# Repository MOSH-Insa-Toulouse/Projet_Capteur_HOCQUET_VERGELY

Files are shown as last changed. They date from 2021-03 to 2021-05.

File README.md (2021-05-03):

# Projet Banc de tests 

## Sommaire
<!-- TOC depthFrom:2 -->
  - [1. Description](#1-description)
  - [2. Installation](#2-installation)
  - [3. Code Arduino](#3-code-arduino)
  - [4. Shield KICAD](#4-shield)
  - [5. Application Android](#5-application-android)
  - [6. Etalonnage](#6-Etalonnage)
  - [7. Datasheet](#7-datasheet)
  - [8. Les auteurs](#8-les-auteurs)
<!-- /TOC -->

## 1. Description
Ce répertoire contient toutes les ressources nécessaires au  projet "du capteur au banc de tests" 2021 du Génie Physique de l'INSA de Toulouse. Ce projet est basé sur l'utilisation d'un capteur en graphite, il exploite la dépendance entre la conductivité électrique et l’espace moyen entre les particules au sein d’un système granuleux. L'application de forces entraîne la déformation de l'échantillion, ce qui affecte la distance entre les particules et donc la variataion de la conductivité/resistance globale de l'échantillion.
La chaîne de mesure est basée sur l'acquisition d'un signal associé à la variation de résistance du capteur. Notre shield permet de conditionner, filtrer et amplifier (ampli transimpédance) le signal afin de transmettre une tension exploitable par une carte arduino UNO. Par ailleurs, il fait aussi le lien entre la carte et les différents modules : module bluetooth, encodeur rotateur, écran oled. 
Les mesures sont aussi transmises en bluetooth et interfacées sur une application mobile que nous avons conçue sur MIT App Inventor.

## 2. Installation

### Préparation du shield 
Utilisez le fichier gerber pour imprimer le shield, puis utilisez le schéma et fiche technique pour le choix et le positionnement des composants. Une fois les composants et les pattes soudées, vous pouvez brancher le shield sur l'arduino UNO.

### Codes 
Vous pouvez ensuite récupérer le code arduino depuis le fichier "Code Arduino" de ce répertoire et directement le téléverser sur la carte. Concernant l'application mobile, il vous suffit de récupérer et d'installer le .apk placé dans le fichier "application mobile" du répertoire.
Vous êtes maintenant prêts à réaliser vos premières mesures !

## 3. Code Arduino

Notre code Arduino (C++) que vous retrouverez dans le fichier du même nom, permet : de lire la tension tension de sortie de l'ampli transimpédance sur 10 bits, d'afficher le signal sur un écran OLED 128x64 en Volts ou en Ohm sur 10 bits, de transmettre la tension par bluetooth sur 1 otect à travers le module hc-05 et d'acquerir les rotations d'un encodeur rotatoire afin de changer l'affichage de l'écran OLED.

## 4. Shield

Le shield a été conçu sous KiCad, il contient un amplificateur transimpédance adapté à notre utilisation, ainsi que des socles pour alimenter et communiquer avec les différents modules. Vous pouvez retrouver l'ensemble du projet, et les fichiers nécessaires à l'impression dans le fichier "Shield_KiCad".

## 5. Application Android

Nous avons prototypé une application mobile capable de recevoir la tension associée à la mesure sur 1 octet et de la traiter. Elle dispose de plusieurs options qui permettent de convertir la tension en resistance, de fixer R0 (la résistance sans contrainte appliquée) et d'afficher en temps réel l'évolution relative de la resistance dans un graphique. Il est aussi possible de régler l'échelle du graphique pour mieux visualiser les variations.

## 6. Etalonnage

Un protocole d'étalonnage conçu spécialement pour notre banc de test est présent dans le fichier "Procédure d'étalonnage", il explique en détail la procédure suivie et le matériel que nous conseillons pour obtenir des résultats optimaux. 

## 7. Datasheet

Les conditions d'utilisation, les résultats attendus,  ainsi que les détails sur chaque partie de la chaîne de mesures sont donnés dans la datasheet que vous pouvez retrouver dans le fichier au même nom. 

## 8. Les auteurs

Projet réalisé par des étudiants en 4 ième année du Génie Physique de l'INSA de Toulouse:

**Henri Hocquet et Fabien Vergely**

- Mail : _henrii.hocquet@gmail.com_

- Mail : _fabien.vergely@gmail.com_

Si vous avez des questions n'hésitez pas ;)

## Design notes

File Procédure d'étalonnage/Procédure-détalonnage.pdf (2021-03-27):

Fabien Vergely Henri Hocquet 4GP

### Procédure d’étalonnage de la chaîne de mesure

Dispositif :

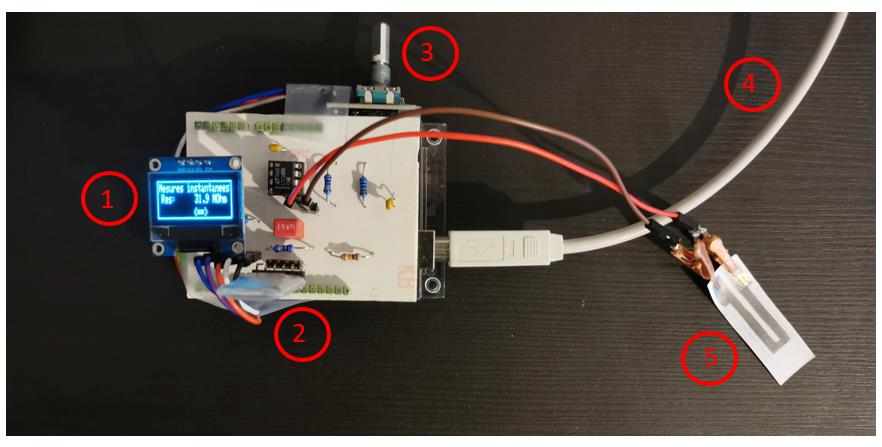
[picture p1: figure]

Notre banc de test est composé d’une carte arduino uno branchée directement en usb sur laquelle on a placé notre shield. Celui-ci fait la liaison avec les différents éléments, mais aussi permet de filtrer et amplifier le signal du capteur.

(1) OLED : Affiche en direct la mesure en Volts ou en Ohm
(2) hc-05 : module Bluetooth pour communiquer avec le téléphone
(3) Roto encodeur : Elément de réglage de l’affichage sur l’oled
(4) USB : Liaison vers le PC
(5) Capteur

On a réalisé l’étalonnage du capteur en traction à l’aide d’un module composé de demi-cylindres concentriques :

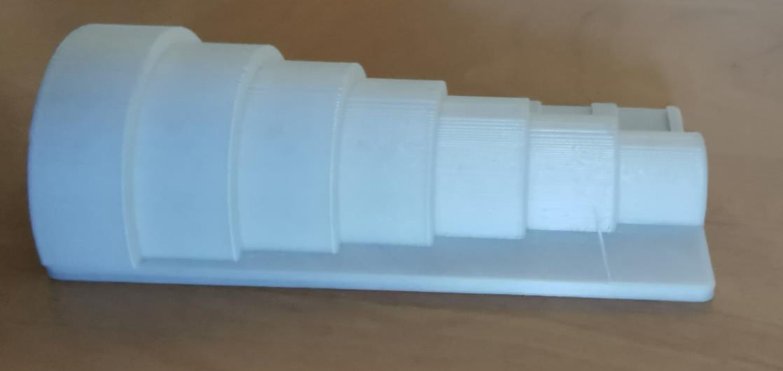
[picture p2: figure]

Fabien Vergely Henri Hocquet 4GP

Les diamètres des cylindres font de 5cm à 2cm par pas de 0,5cm.

Procédure d’étalonnage en traction :

-On place les pinces capteur crocodile sur le capteur

-On vérifie que le signal mesuré soit supérieur à 1V, si ce n’est pas le cas on rajoute du crayon sur le capteur

(Au fil de nos tests, on a pu observer que si le V0 est déjà très faible, le capteur s’endommage très rapidement en traction et la valeur pour d’importantes déformations est noyée dans le bruit)

-On place le capteur sur le cylindre le plus grand et on attend 2 secondes avant de relever la valeur

-On répète l’opération de cylindre en cylindre du plus gros au plus petit afin de limiter l’effet de la détérioration du capteur

Lien entre la déformation et le rayon des cylindres :

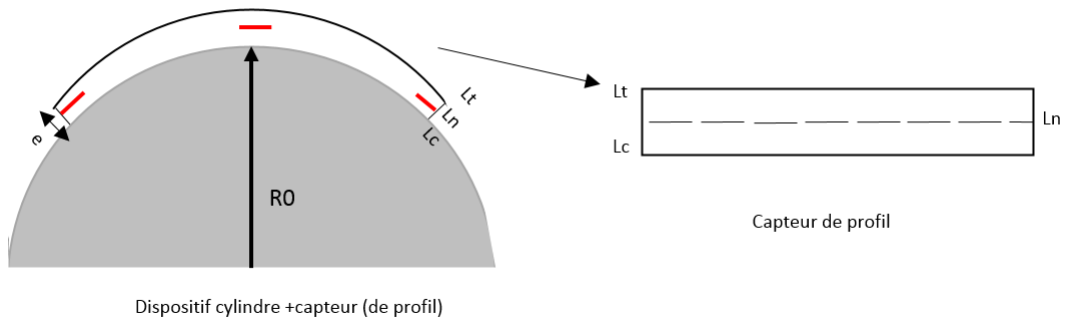
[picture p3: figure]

On peut facilement démonter que : ε =

Lt−Ln
Ln

≅

e
2R0
On considère l’épaisseur du papier e=1mm et on connait les rayons R0 de chacun des cylindres.

On peut alors tracer une courbe d’étalonnage telle que : R=f(ε) (voir doc Mesures étalonnage)

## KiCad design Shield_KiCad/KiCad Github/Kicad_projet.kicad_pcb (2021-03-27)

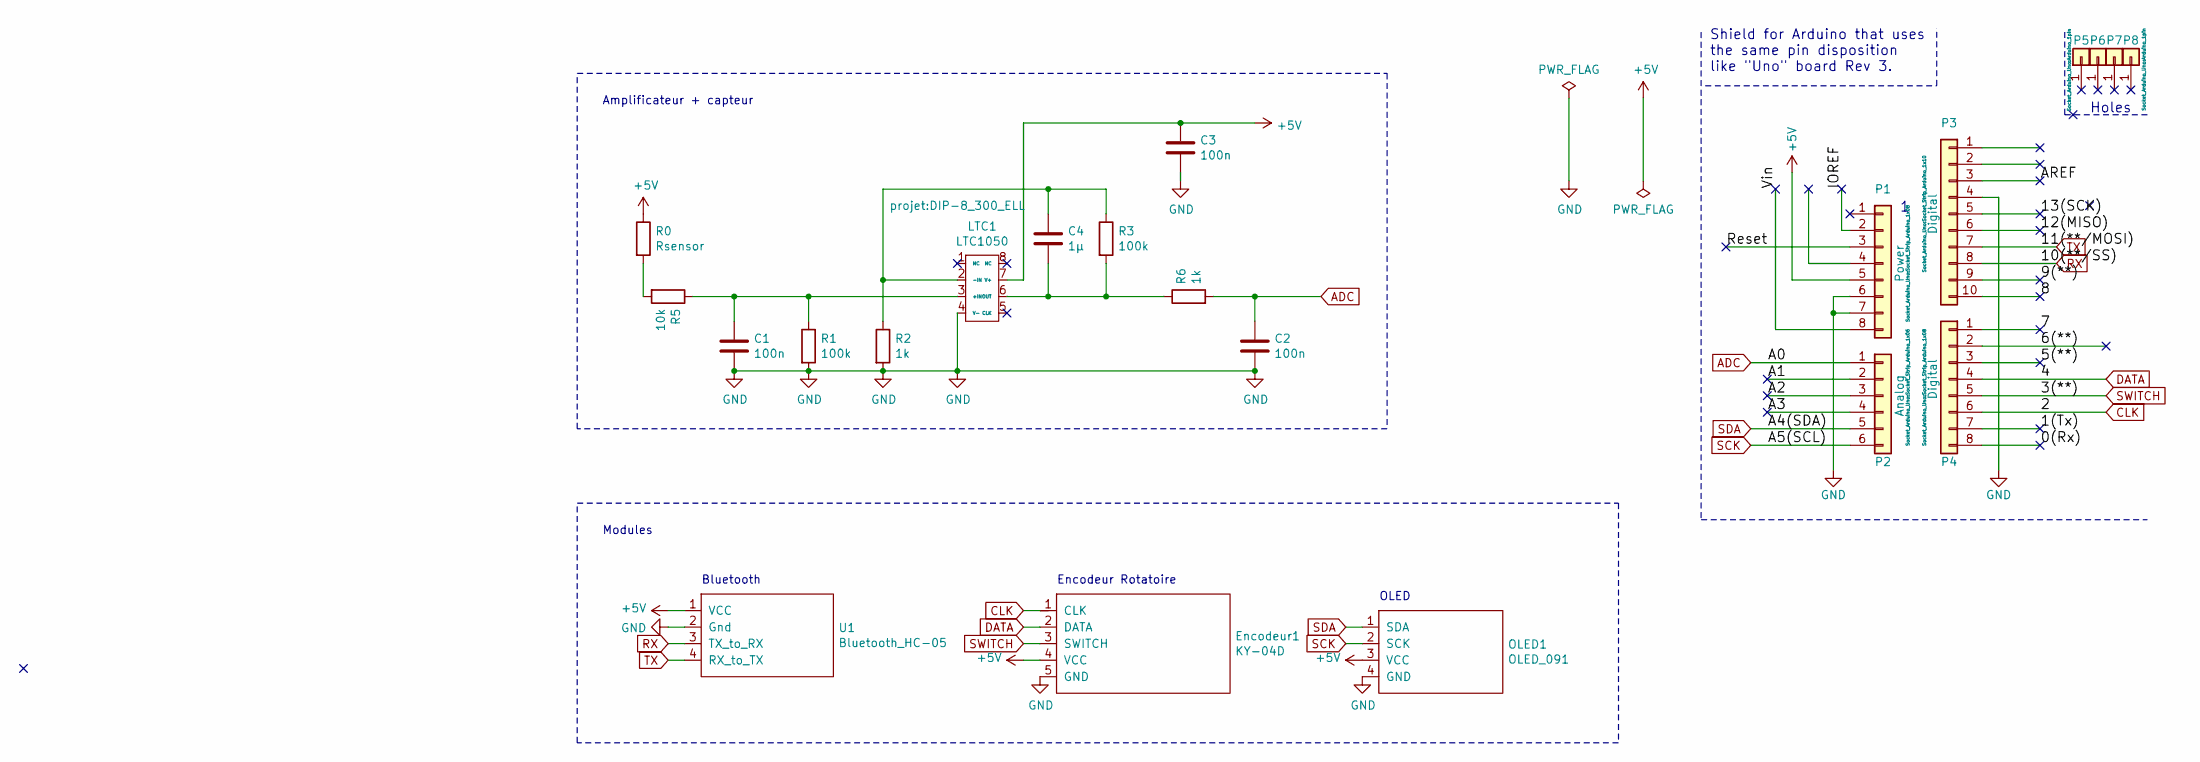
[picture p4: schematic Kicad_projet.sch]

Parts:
C1, C2, C3: 100n; C_Disc_D3.0mm_W1.6mm_P2.50mm
C4: 1µ; C_Rect_L7.0mm_W3.5mm_P5.00mm
Encodeur1: KY-04D; Encodeur
LTC1: LTC1050; DIP-8_300_ELL
OLED1: OLED_091; OLED
P1: Power; Socket_Strip_Arduino_1x08
P2: Analog; Socket_Strip_Arduino_1x06
P3: Digital; Socket_Strip_Arduino_1x10
P4: Digital; Socket_Strip_Arduino_1x08
P5, P6, P7, P8: CONN_01X01; Arduino_1pin
R0: Rsensor; R_Axial_DIN0204_L3.6mm_D1.6mm_P2.54mm_Vertical
R1, R3: 100k; R_Axial_DIN0309_L9.0mm_D3.2mm_P12.70mm_Horizontal
R2, R6: 1k; R_Axial_DIN0309_L9.0mm_D3.2mm_P12.70mm_Horizontal
R5: 10k; R_Axial_DIN0309_L9.0mm_D3.2mm_P12.70mm_Horizontal
U1: Bluetooth_HC-05

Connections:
+5V: C3.1, Encodeur1.4 (VCC), LTC1.7 (V+), OLED1.3 (VCC), P1.5, R0.1, U1.1 (VCC)
/0(Rx): P4.8
/1(Tx): P4.7
/5(**): P4.3
/6(**): P4.2
/7: P4.1
/8: P3.10
/9(**): P3.9
/12(MISO): P3.6
/13(SCK): P3.5
/A1: P2.2
/A2: P2.3
/A3: P2.4
/AREF: P3.3
/IOREF: P1.2
/Reset: P1.3
/Vin: P1.8
ADC: C2.1, P2.1, R6.2
CLK: Encodeur1.1 (CLK), P4.6
DATA: Encodeur1.2 (DATA), P4.4
GND: C1.2, C2.2, C3.2, Encodeur1.5 (GND), LTC1.4 (V-), OLED1.4 (GND), P1.6, P1.7, P3.4, R1.2, R2.2, U1.2 (Gnd)
unnamed: C1.1, LTC1.3 (+IN), R1.1, R5.1
unnamed: C4.1, LTC1.2 (-IN), R2.1, R3.1
unnamed: C4.2, LTC1.6 (OUT), R3.2, R6.1
unnamed: R0.2, R5.2
RX: P3.8, U1.3 (TX_to_RX)
SCK: OLED1.2 (SCK), P2.6
SDA: OLED1.1 (SDA), P2.5
SWITCH: Encodeur1.3 (SWITCH), P4.5
TX: P3.7, U1.4 (RX_to_TX)

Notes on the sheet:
Holes
Shield for Arduino that uses the same pin disposition like "Uno" board Rev 3.
Amplificateur + capteur
Modules
Bluetooth
Encodeur Rotatoire
OLED

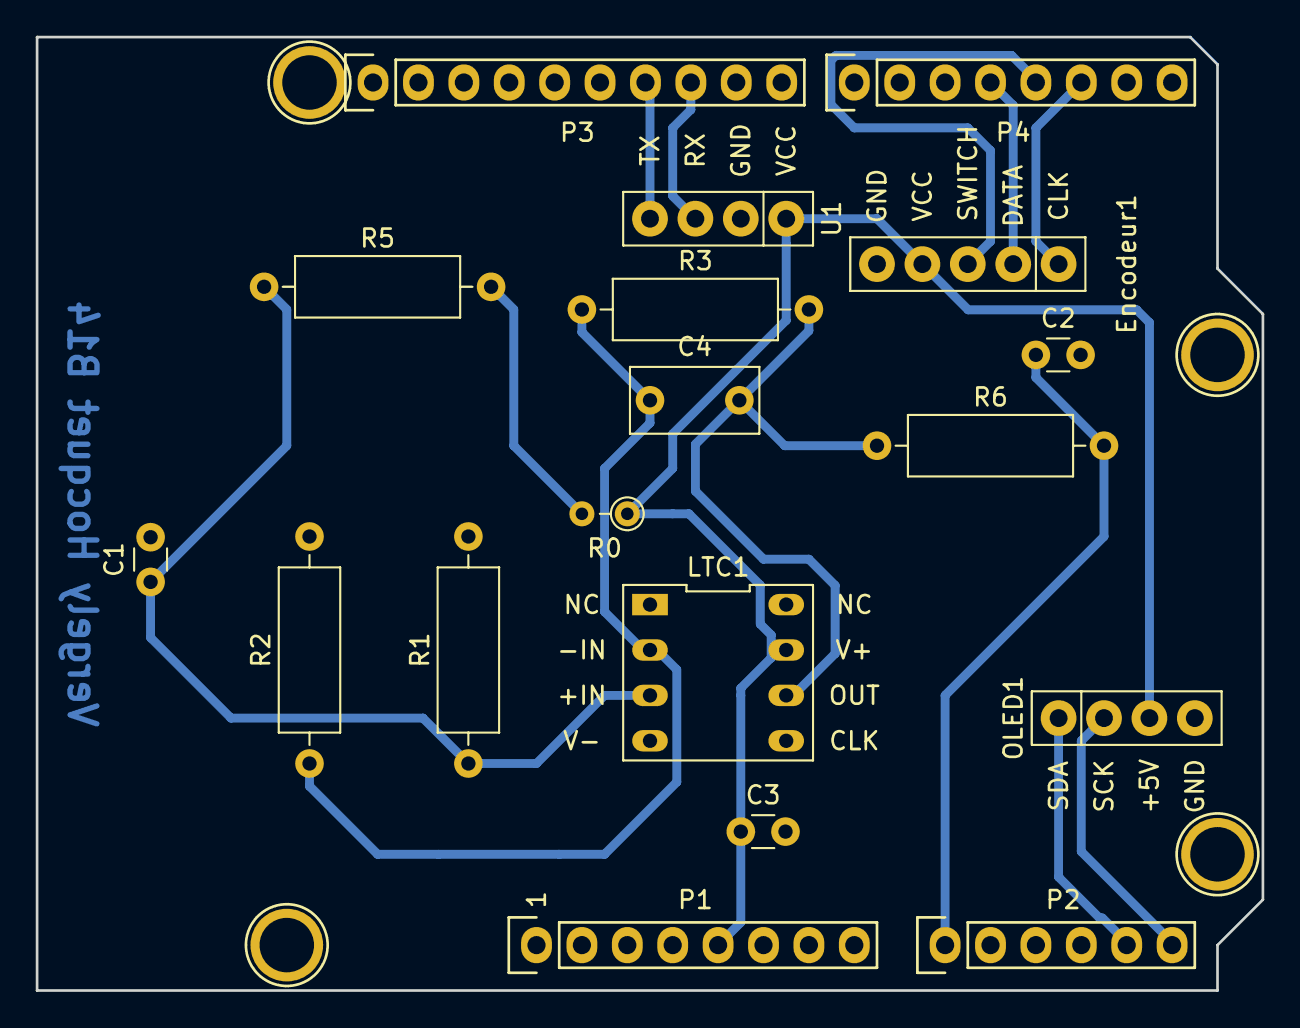
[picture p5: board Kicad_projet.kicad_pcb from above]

Board: 2 copper layers, 68.6 x 53.3 mm, 22 parts (0 on the bottom side), 14 nets.

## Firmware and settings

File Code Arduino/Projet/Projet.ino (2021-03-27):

//Importation des bibliotèques relatives aux différents modules
#include <SoftwareSerial.h>
#include <SPI.h>
#include <Wire.h>
#include <Adafruit_GFX.h>
#include <Adafruit_SSD1306.h>
#include <stdio.h>
#include <math.h>

//Configuration de l'OLED
#define OLED_RESET 4
Adafruit_SSD1306 display(OLED_RESET);
#define NUMFLAKES 10
#define XPOS 0
#define YPOS 1
#define DELTAY 2
double count=0;
#define LOGO16_GLCD_HEIGHT 32
#define LOGO16_GLCD_WIDTH  128 
#if (SSD1306_LCDHEIGHT != 32)
#error("Height incorrect, please fix Adafruit_SSD1306.h!");
#endif

//Configuration de la liaison série avec le module HC-05
#define rxPin 10 //Broche 10 en tant que RX, à raccorder sur TX du HC-05
#define txPin 11 //Broche 11 en tant que RX, à raccorder sur TX du HC-05
#define baudrate 9600
SoftwareSerial mySerial(rxPin ,txPin); //Définition du software serial
int Analog_Pin = 0; 

//Configuration des pins utilisés par l'encodeur
#define encoder0PinA  2  //CLK Output A Do not use other pin for clock as we are using interrupt
#define encoder0PinB  4  //DT Output B
#define Switch 3 // Switch connection if available
volatile unsigned int encoder0Pos = 0;


void setup()   {    
              
  //HC-05
  Serial.begin(9600); //choix de baudrate
  mySerial.begin(baudrate);
  Serial.begin(baudrate);
  
  //Initialistion de l'OLED
  display.begin(SSD1306_SWITCHCAPVCC, 0x3C);  // initialize with the I2C addr 0x3C (for the 128x32)
  display.display();
  delay(100);
  
  //encodeur
    pinMode(encoder0PinA, INPUT); 
   digitalWrite(encoder0PinA, HIGH);       // turn on pullup resistor

   pinMode(encoder0PinB, INPUT); 
   digitalWrite(encoder0PinB, HIGH);       // turn on pullup resistor

   attachInterrupt(0, doEncoder, RISING); // encoder pin on interrupt 0 - pin2

  
}


void loop() {
  
  //lecture et transimision 
  int valeur1=analogRead(0); //lecture de la valeur sur 10bits
  byte valeur = map(valeur1,0,1024,0,255); //conversion sur 8bits pour la valeur qui est transmise en BT
  Serial.println(valeur);       //affichage invité de commande ->10bits
  mySerial.write(valeur);     //transmission hc-05 ->8bits
  delay(200);   

    //affichage sur l'oled
  display.clearDisplay();
  float valeur2;
  valeur2=(valeur1*5)/1024.0; //calcul de la valeur correspondante en Volts (à partir de la valeur sur 10 bits)
  float res=((505.0*pow(10,5))/valeur2)-(110.0*pow(10,3)); //calcul de la valeur correspondante en Ressistance (à partir de la valeur sur 10 bits)
  res=res/pow(10,6); //passage de la megaohm pour simplifier l'affichage (à partir de la valeur sur 10 bits)
  String aff=String(valeur2,3); //Conversion en string de la valeur en Volts 
  String aff2=String(res,1);//Conversion en string de la valeur en resistance
  Text("Mesures instantanees", 4, 3, 1, false); //Affichage du titre en postion haute
  Text("<==>", 62, 23, 1, false); //Affichage des flèches en position basse
 
  //Selon ce que retourne la fonction responsable de signaler les rotations de l'encodeur, l'oled va afficher soit la valeur en volts, soit en ohm
  if(encoder0Pos==0){        //Premier cas en Volts
    Text("Voltage:          ", 4, 12, 1, false);
    Text(aff, 72, 12, 1, false);
    Text("V", 110, 12, 1, false);
  }
  else{                   
     Text(" Res:          ", 2, 12, 1, false); //Deuxième cas en Ohm
    Text(aff2, 65, 12, 1, false);
    Text("MOhm", 95, 12, 1, false);
  }
  
  
  display.drawRect(1, 1, 126,31, WHITE); //Affichage du cadre rectangulaire dans l'oled
  display.display();
  count +=0.173;
  

  
}

 //Fonctions

 //Fonction permettant d'afficher un string dans l'oled à l'endroit et la taille de son choix
void Text(String text, int x, int y,int size, boolean d) {

  display.setTextSize(size);
  display.setTextColor(WHITE);
  display.setCursor(x,y);
  display.println(text);
  if(d){
    display.display();
  }
}

//Fonction responsable de la détection et di signalement de variation d'angle de l'encodeur
void doEncoder() {
  if (digitalRead(encoder0PinB)==HIGH) { //si une variation est remarquée
    if(encoder0Pos==0) //si la variable valait 0
      encoder0Pos=1; //on la passe à 1
     else
      encoder0Pos=0; //sinon on la met à 0
  }
}
